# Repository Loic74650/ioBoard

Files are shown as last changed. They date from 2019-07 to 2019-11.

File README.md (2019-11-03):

<h2>ioBoard v1.2</h2>
<h2>I/O board with Ethernet connectivity for home automation applications</h2>
<br />
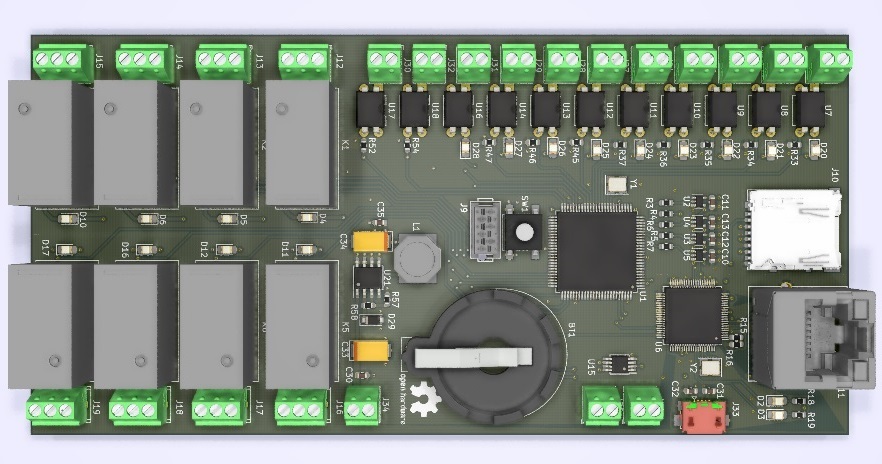
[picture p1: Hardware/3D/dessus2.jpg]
Overview
 <br /><br />
<br />
<h4>Brief description</h4>
<p>Simply put, ioBoard is a mix between an Arduino Mega board, the Ethernet shield and the relay shield + some small additional features (RTC, opto-isolation of digital inputs/outputs, two analog inputs, one Teleinfo input…).<br />
It supports the MQTT protocol and has a set of API functions so that it is easy to control it over the Ethernet for home automation applications for instance.<br />
ioBoard can be programmed to perform tasks at regular intervals such as water the garden or switch on a pump autonomously. <br />
ioBoard also has input pulse counters, typically used to track the consumption of a gas or oil heater, water or even electrical consumption.<br />
ioBoard also has a TeleInfo input, which is a French dedicated energy meter interface to the main electric meter of the house.<br />
Finally, ioBoard has a small web server stored on an SD card, in order to reflect the status of the board I/Os.</p> <br />

<h4>Main specs:</h4>
<p>
<ul>
<li>Atmega2560 16MHz µC</li>
<li>programmable with Arduino IDE (with USB interface)</li>
<li>Ethernet 10M/100M RJ45 internet interface</li>
<li>x8 Relay outputs 230VAC/30VDC 10A – Form-C relays, screw terminal and SMD Status-LED for each (opto-isolated from µC)</li>
<li>x8 opto-isolated digital inputs with SMD Status-LEDs (internal pull-up, HIGH level by default. Ground the input to make it LOW)</li> 
<li>x2 10 bits analog inputs 0-3.3VDC</li>
<li>x2 opto-isolated digital input pulse counters (internal pull-up by default. Ground the input to increment it. Input low-pass filtered at 10Hz max.)</li> 
<li>x1 opto-isolated Télé-Info input</li> 
<li>RTC module (DS1307) for time management with on-board Lithium back-up battery</li> 
<li>Micro SD card slot (Web server) </li>
<li>DIN rail format (PCB Size 143mm x 72mm)</li>
</ul>
</p><br />

<h4>Getting started</h4>
<p>
Before compiling the code and flashing it onto the µC, make sure you have changed the following variables in the code:<br /> 
<ul>
<li>MAC address of the board</li>
<li>IP address of the MQTT broker</li>
<li>Credentials to log into the MQTT broker</li>
</ul>
</p><br />

<h4>MQTT API</h4>
<p>
Below are the Payloads/commands to publish on the "ioBoard/API" topic in Json format in order to launch actions on the ioBoard:<br />
<ul>
<li>{"SetRelayMode":[3,1,500]} -> set the operating mode for a relay. 0 is standard operating mode (ON/OFF) and 1 is PULSE mode. In pulse mode, after a relay has been switched ON, it will automatically switch back to OFF state after a defined time in millisecs. In this example, relay #3 is set to PULSE mode with a switch back time of 500ms</li> 
<li>{"SetRelay":[4,1]}      -> set state of a defined relay. In this example, relay #4 is set to 1</li> 
<li>{"SetRelays":15}        -> set all relays states at once by sending a Byte. Each individual bit reflects the status of one relay. In this example, the first four relays are switched ON and the last four are switched OFF (15 in decimal form corresponds to 00001111 in binary form)</li> 
<li>{"SetC0":0}        		-> set initial value of Counter #0</li>
<li>{"SetC1":2140}        	-> set initial value of Counter #1</li>
<li>{"SetDate":[1,1,1,18,13,32,0]}      -> set date/time of RTC module in the following format: (Day of the month, Day of the week, Month, Year, Hour, Minute, Seconds), in this example: Monday 1st January 2018 - 13h32mn00secs</li>
</ul>
<br />

The status of the I/Os is published on the "ioBoard/IOs" topic in the following Json format:<br />
<ul>
<li>{"Relays":15}       	-> A Byte representing all the relays states. Each individual bit reflects the status of one relay. In this example, the first four relays are ON and the last four are OFF (15 in decimal form corresponds to 00001111 in binary form)</li>
<li>{"DIns":127}       		-> A Byte representing all the digital input states. Each individual bit reflects the status of one input. In this example, the first input state is FALSE and the last seven are TRUE (127 in decimal form corresponds to 01111111 in binary form)</li>
<li>{"C0":1203}       		-> Value of Counter0</li>
<li>{"C1":0}       			-> Value of Counter1</li>
<li>{"AI":[1203,0]}       	-> Values of the Analog Inputs. In this example, AI0 is 1203 and AI1 is 0</li>
<li>{"TI":[ADCO,OPTARIF,ISOUSC,BASE,IINST,PAPP,ADPS,IMAX,PTEC]}      -> TeleInfo data. Refer to this link for more info: https://www.enedis.fr/sites/default/files/Enedis-NOI-CPT_02E.pdf</li>
</ul>
<br />

The above Json commands representing the state of the I/Os are updated as soon as a Digital I/O changes state or every 30 secs for the Analog Inputs.
</p><br />

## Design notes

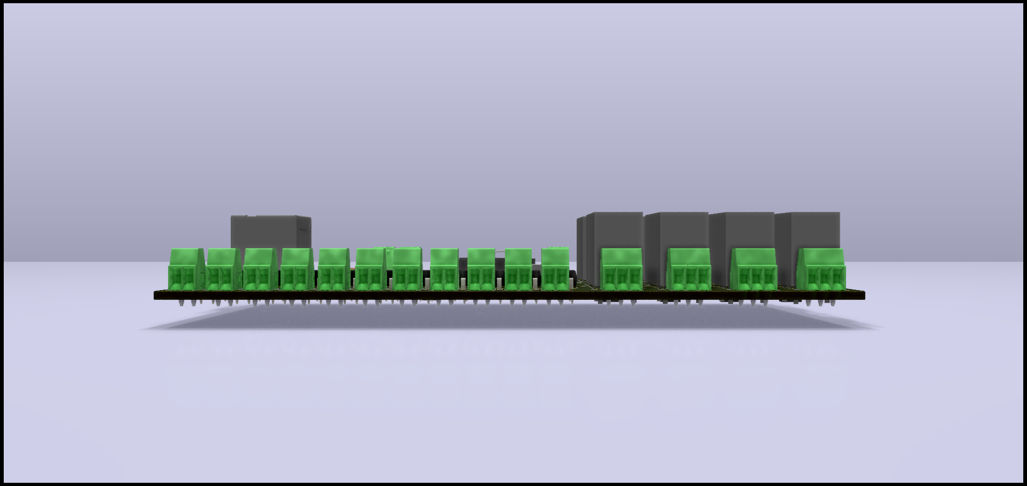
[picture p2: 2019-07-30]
Hardware/3D/gauche.png

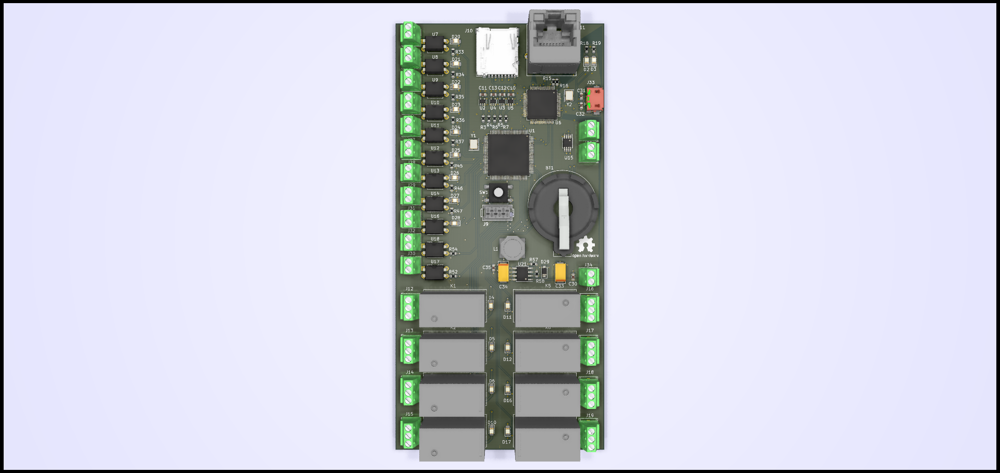
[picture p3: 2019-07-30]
Hardware/3D/dessus.png

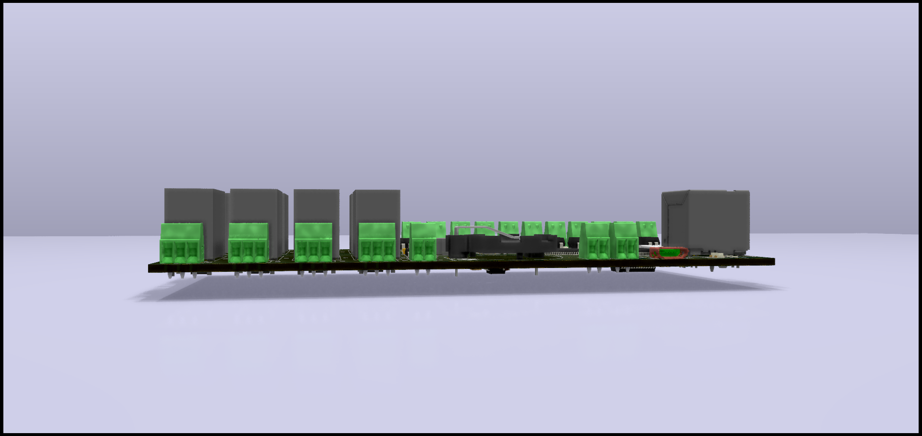
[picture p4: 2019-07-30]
Hardware/3D/droite.png

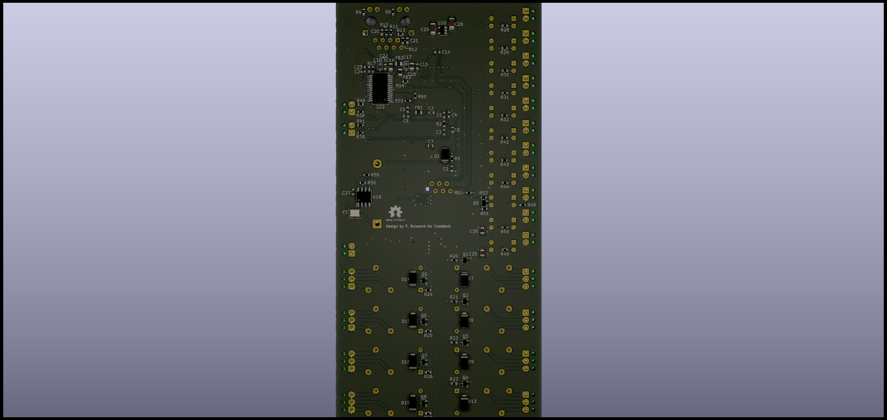
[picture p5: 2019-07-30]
Hardware/3D/dessous.png

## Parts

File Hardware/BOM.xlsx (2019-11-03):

Date: | 2019-06-19
Tool: | Eeschema (5.0.2)-1
Generator: | C:\Program Files\KiCad\bin\scripting\plugins/bom_csv_grouped_by_value_with_fp.py
Component Count: | 188
Ref | Qnty | Value | Cmp name | Footprint | Description | Farnel n° | Prix unitaire | Total
 | 1 | CR2025 | Battery_Cell |  | ~ | 2065170 | 0.52 € | 0.52 €
BT1 | 1 | 103 | KEYSTONE |  |  | 676469 | 2.79 € | 2.79 €
C1, C23, C24, | 3 | 22pF | C |  | Unpolarized capacitor | 2309012 | 0.05 € | 0.16 €
C3, C4, | 2 | 15pF | C |  | Unpolarized capacitor | 1759055 | 0.05 € | 0.09 €
C7, C6, C5, C2, C9, C8, C14, C21, C20, C15, C22, C27, C30, C35, C36 | 14 | 100nF | C |  | Unpolarized capacitor | 2210925 | 0.05 € | 0.65 €
C12, C10, C13, C11, | 4 | 10nF | C |  | Unpolarized capacitor | 9406182 | 0.02 € | 0.08 €
C16, C19, C25, C26, | 4 | 1uF | C |  | Unpolarized capacitor | 2896564 | 0.06 € | 0.25 €
C31, C32, | 2 | 47pF | C |  | Unpolarized capacitor | 1759062 | 0.05 € | 0.10 €
C29, C28, | 2 | 1µF | CP |  | Polarized capacitor | 2491457 | 0.24 € | 0.49 €
C33, C34 | 2 | 10µF | CP |  | Polarized capacitor | 2462775 | 0.22 € | 0.43 €
C17, C18, | 2 | 10µF | CP |  | Polarized capacitor | 2491430 | 0.31 € | 0.63 €
D1, | 1 | RSFBL R3 | DIODE |  | Diode symbol for simulation only. Pin order incompatible with official kicad footprints | 1559142 | 0.09 € | 0.09 €
D2, D3, D6, D11, D10, D16, D5, D12, D17, D4, D20, D21, D22, D23, D24, D25, D26, D27, D28 | 19 | LED | KP-2012LSGC |  | Light emitting diode | 2463991 | 0.09 € | 1.68 €
D9, D14, D13, D18, D8, D15, D19, D7, | 8 | S1JL R3 | DIODE |  | Diode symbol for simulation only. Pin order incompatible with official kicad footprints | 1559153 | 0.07 € | 0.56 €
D29 | 1 | NRVTS2H60ESFT3G |  |  |  | 3003776 | 0.18 € | 0.18 €
FB1, | 1 | 10 µH | Ferrite_Bead_Small |  | Ferrite bead, small symbol | 2215650 | 0.11 € | 0.11 €
FB3, FB2, | 2 | MH2029-300Y | Ferrite_Bead_Small |  | Ferrite bead, small symbol | 2859248 | 0.07 € | 0.13 €
J9, | 1 | ICSP | Conn_02x03_Odd_Even |  | Generic connector, double row, 02x03, odd/even pin numbering scheme (row 1 odd numbers, row 2 even numbers), script generated (kicad-library-utils/schlib/autogen/connector/) | 2473349 | 0.27 € | 0.27 €
J10, | 1 | Micro_SD_Card | Micro_SD_Card |  | Micro SD Card Socket | 2427719 | 1.83 € | 1.83 €
J11, | 1 | 8P8C_LED_Shielded | 8P8C_LED_Shielded |  | RJ connector, 8P8C (8 positions 8 connected), two LEDs, RJ45, Shielded | 2891063 | 1.22 € | 1.22 €
J14, J16, J15, J18, J13, J17, J19, J12, | 8 | MPT 0.5/3-2.54 | Screw_Terminal_01x03 |  | Generic screw terminal, single row, 01x03, script generated (kicad-library-utils/schlib/autogen/connector/) | 3041360 | 1.02 € | 8.16 €
J20, J21, J22, J23, J24, J27, J28, J29, J25, J26, J30, J32, J31, J34 | 14 | MPT 0.5/2-2.54 | Screw_Terminal_01x02 |  | Generic screw terminal, single row, 01x02, script generated (kicad-library-utils/schlib/autogen/connector/) | 3041359 | 0.72 € | 10.14 €
J33, | 1 | micro USB | micro USB |  |  | 2751674 | 0.27 € | 0.27 €
K3, K5, K4, K7, K2, K6, K8, K1, | 8 | OMI-SH-112LM | G5Q-1EU |  | Ultra-miniature, Highly Sensitive SPDT Relay for Signal Circuits | 4446434 | 0.78 € | 6.23 €
L1 | 1 | 47µH | SRU8043 |  |  | 2859240 | 0.78 € | 0.78 €
Q3, Q5, Q4, Q7, Q2, Q6, Q8, Q1, Q9, | 9 | RU1C001UNTCL | Q_NMOS_GSD |  | N-MOSFET transistor, gate/source/drain | 2706680 | 0.09 € | 0.80 €
R1, R38, R40, R39, R41,R53, R56, R55, R57, R58, R62, R63, R64, R65, R66, R67 | 18 | 10K | R |  | Resistor | 2447230 | 0.01 € | 0.18 €
R2, R17, | 2 | 1M | R |  | Resistor | 2073358 |  | 0.00 €
R5, R7, R4, R6, R3, R14, R59, R60, | 8 | 100 | R |  | Resistor | 2694684 | 0.01 € | 0.08 €
R9, R8, R18, R19, R22, R24, R23, R26, R21, R25, R27, R20, | 11 | 1K | R |  | Resistor | 2694685 | 0.01 € | 0.09 €
R13, R12, R11, R10, | 4 | 49.9 | R |  | Resistor | 2447381 | 0.01 € | 0.04 €
R15, | 1 | 12K | R |  | Resistor | 2447243 | 0.01 € | 0.01 €
R16, | 1 | 300 | R |  | Resistor | 2073463 | 0.01 € | 0.01 €
R28, R29, R30, R31, R32, R42, R43, R44, R49, R50, | 10 | 510 | R |  | Resistor | 1469826 | 0.01 € | 0.10 €
R33, R34, R35, R37, R45, R46, R47, R36, R51 | 9 | 1K5 | R |  | Resistor | 2694727 | 0.01 € | 0.09 €
R48, | 1 | 4.7K | R |  | Resistor | 2447385 | 0.01 € | 0.01 €
R54, R52 | 1 | 15K | R |  | Resistor | 2861871 | 0.01 € | 0.01 €
SW1, | 1 | SW_DPST | SW_DPST |  | Double Pole Single Throw (DPST) Switch | 1181017 | 0.63 € | 0.63 €
U1, | 1 | ATmega2560 | ATmega2560-16AU |  | 16MHz, 256kB Flash, 8kB SRAM, 4kB EEPROM, JTAG, TQFP-100 | 1288330 | 10.13 € | 10.13 €
U3, U5, U2, U4, | 4 | 74AHC1G125 | 74AHC1G125 |  | Single Buffer Gate Tri-State, Low-Voltage CMOS | 1893809 | 0.20 € | 0.81 €
U6, | 1 | W5100 | W5100 |  | 10/100Mb Ethernet controller with TCP/IP stack, LQFP-80 |  |  | 5.13 €
U7, U8, U9, U10, U11, U12, U13, U14, U17, U18, | 10 | SFH617A-1 | SFH617A-1 |  | Optocoupler, Phototransistor Output, 5300 VRMS, VCEO 70V, CTR% 40-80, -55 to +110 degree Celcius, UL, BSI, FIMKO, cUL, THT PDIP-4 | 1612481 | 0.26 € | 2.61 €
U16, | 1 | SFH620A-1 | SFH620A-1 |  | Optocoupler, Phototransistor Output, 5300 VRMS, VCEO 70V, CTR% 40-80, -55 to +110 degree Celcius, UL, BSI, FIMKO, cUL, THT PDIP-4 | 1683360 | 0.72 € | 0.72 €
U15, | 1 | LM2904 | LM2904 |  | Low-Power, Dual-Operational Amplifiers, DIP-14/SOIC-14/SSOP-14 | 2709555 | 0.18 € | 0.18 €
U19, | 1 | DS1307+ | DS1307+ |  | 64 x 8, Serial, I2C Real-time clock, 4.5V to 5.5V VCC, 0Â°C to +70Â°C, DIP-8 | 2798723 | 2.81 € | 2.81 €
U20, | 1 | MIC5504-3.3YM5 | MIC5504-3.3YM5 |  | 300mA Low-dropout Voltage Regulator, Vout 3.3V, Vin up to 5.5V, SOT-23 | 2510377 | 0.10 € | 0.10 €
U21, | 1 | AP1509 | AP1509 |  |  | 1825323 | 1.18 € | 1.18 €
U22, | 1 | FT232RL | FT232RL |  |  | 1146032 | 3.93 € | 3.93 €
Y1, | 1 | 16MHz | Crystal |  | Two pin crystal | 2909954 | 0.75 € | 0.75 €
Y2, | 1 | 25MHz | Crystal |  | Two pin crystal | 2909963 | 0.35 € | 0.35 €
Y3, | 1 | 32.768KHz | Crystal |  | Two pin crystal | 2819305 | 0.34 € | 0.34 €
 |  |  |  |  |  |  | TOTAL | 65.61 €

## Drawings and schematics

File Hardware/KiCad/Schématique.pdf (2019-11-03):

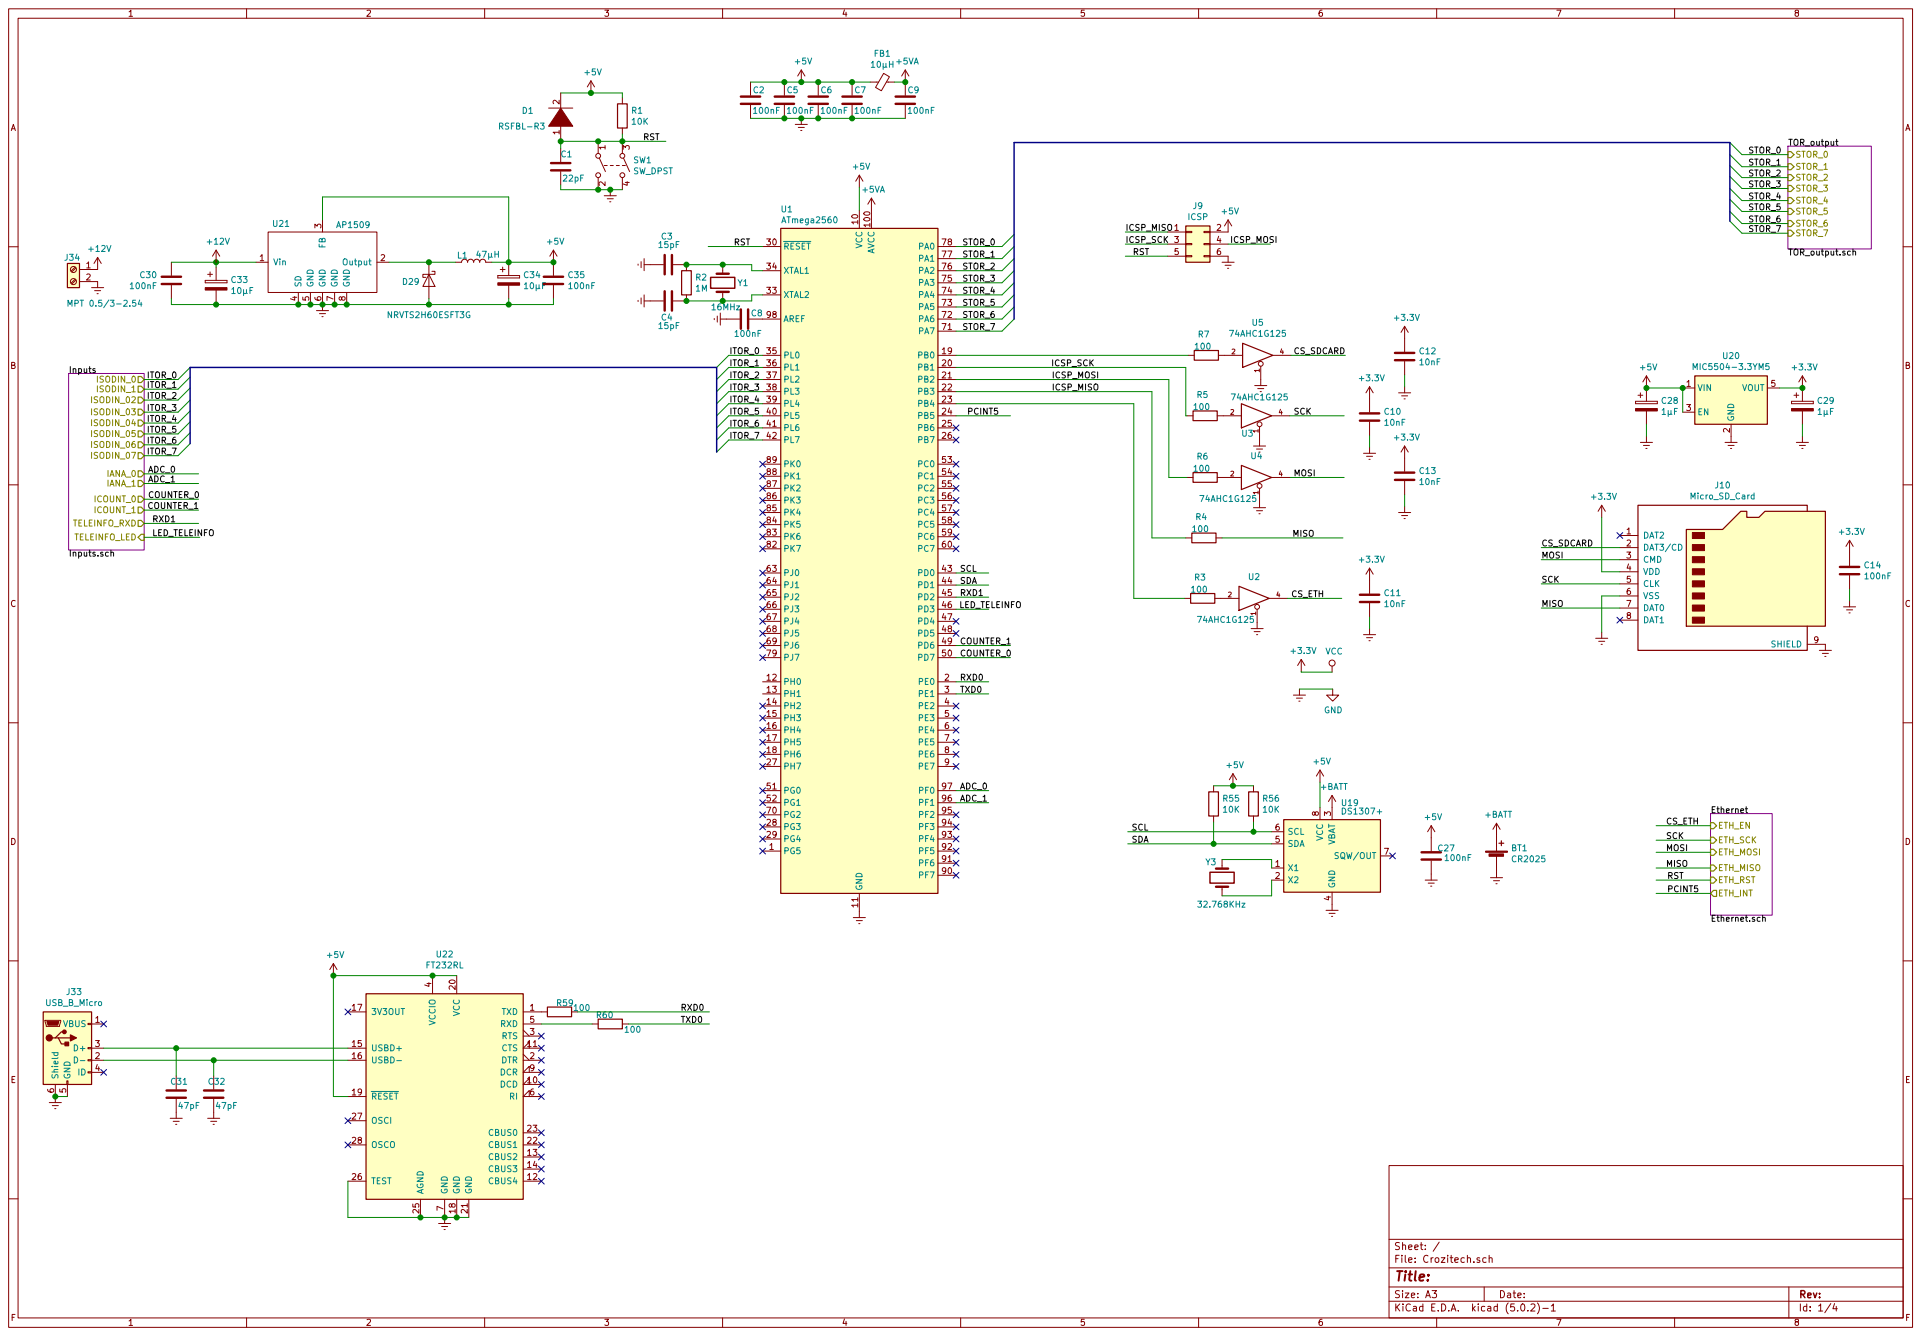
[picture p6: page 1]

4 SDA 5 SCL 6 SQW/OUT 7 VCC

Id: 1/4 Title: File: Crozitech.sch Sheet: /

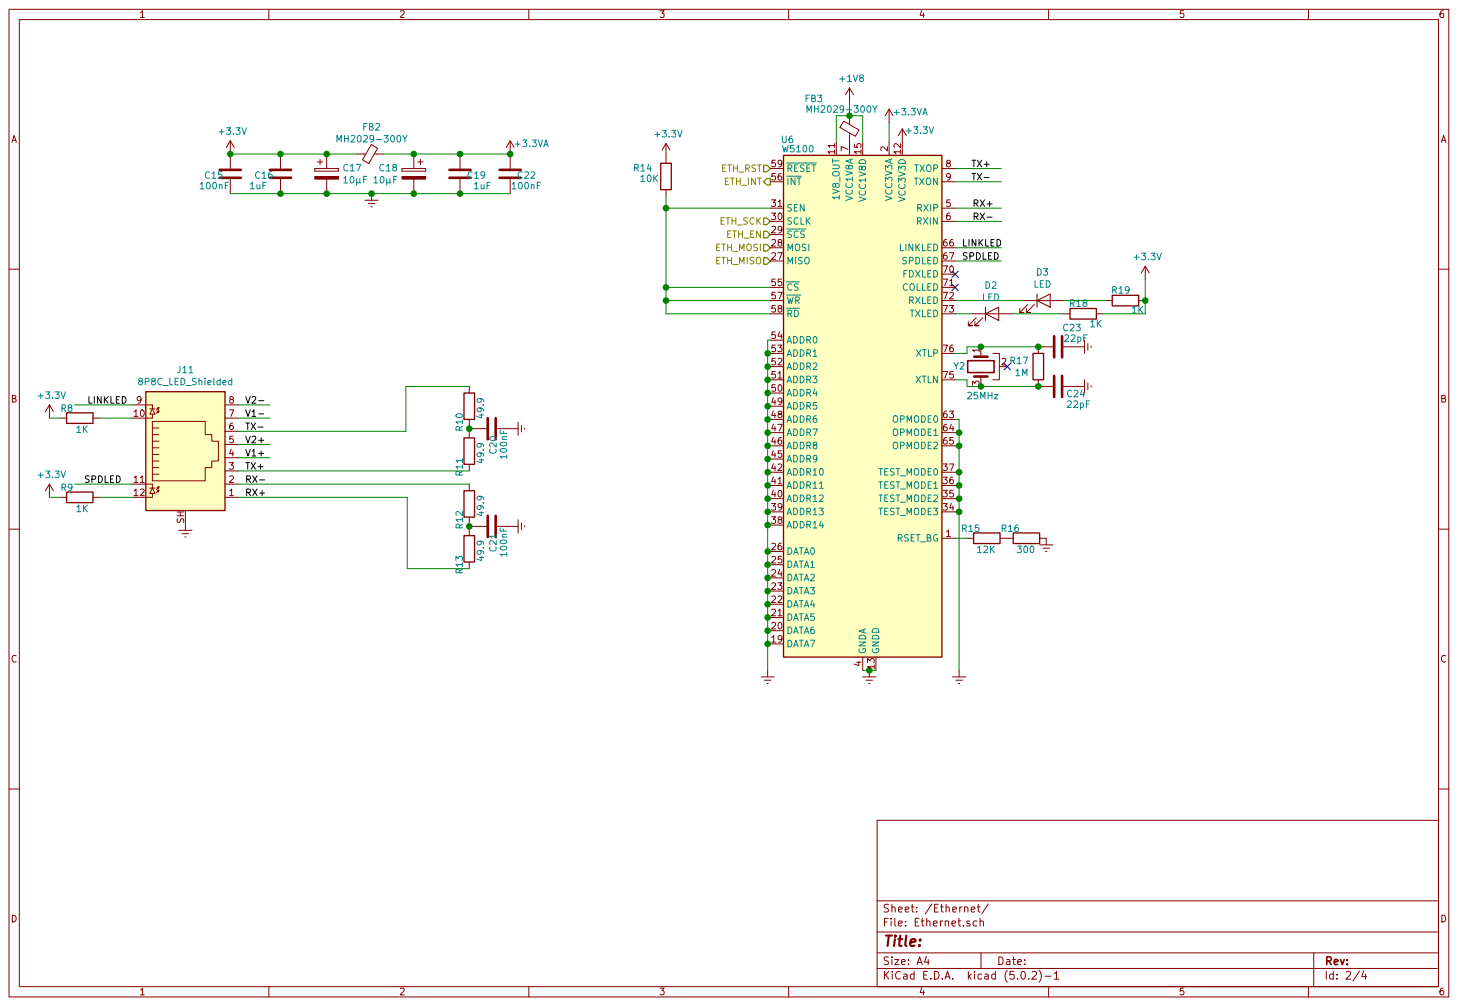
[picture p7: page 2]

Id: 2/4 Title: File: Ethernet.sch Sheet: /Ethernet/ 1

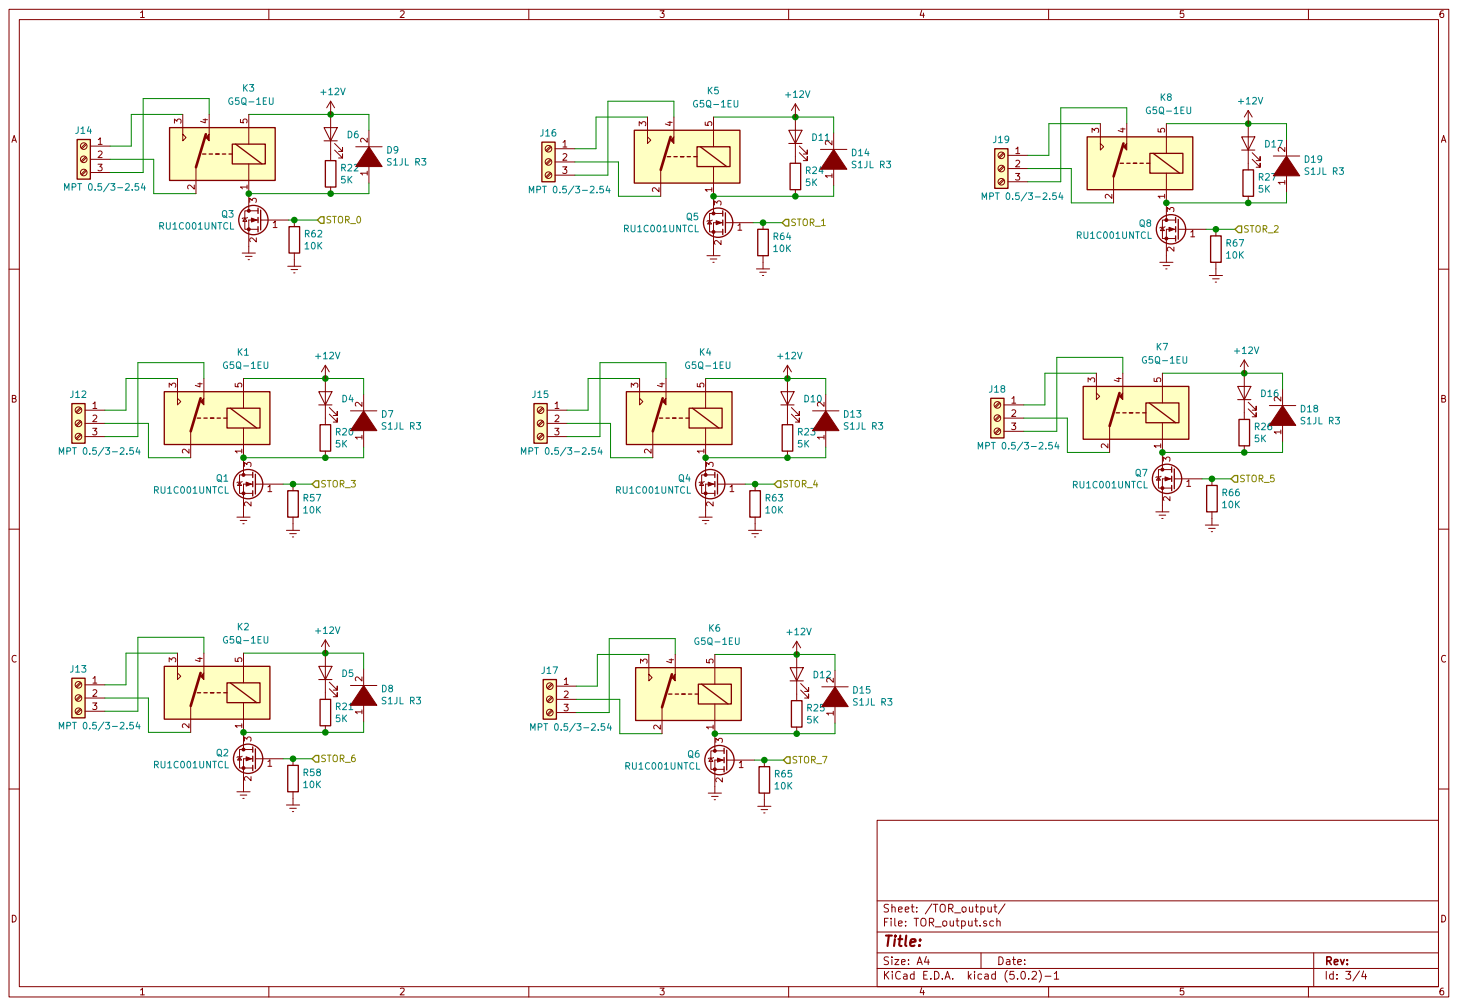
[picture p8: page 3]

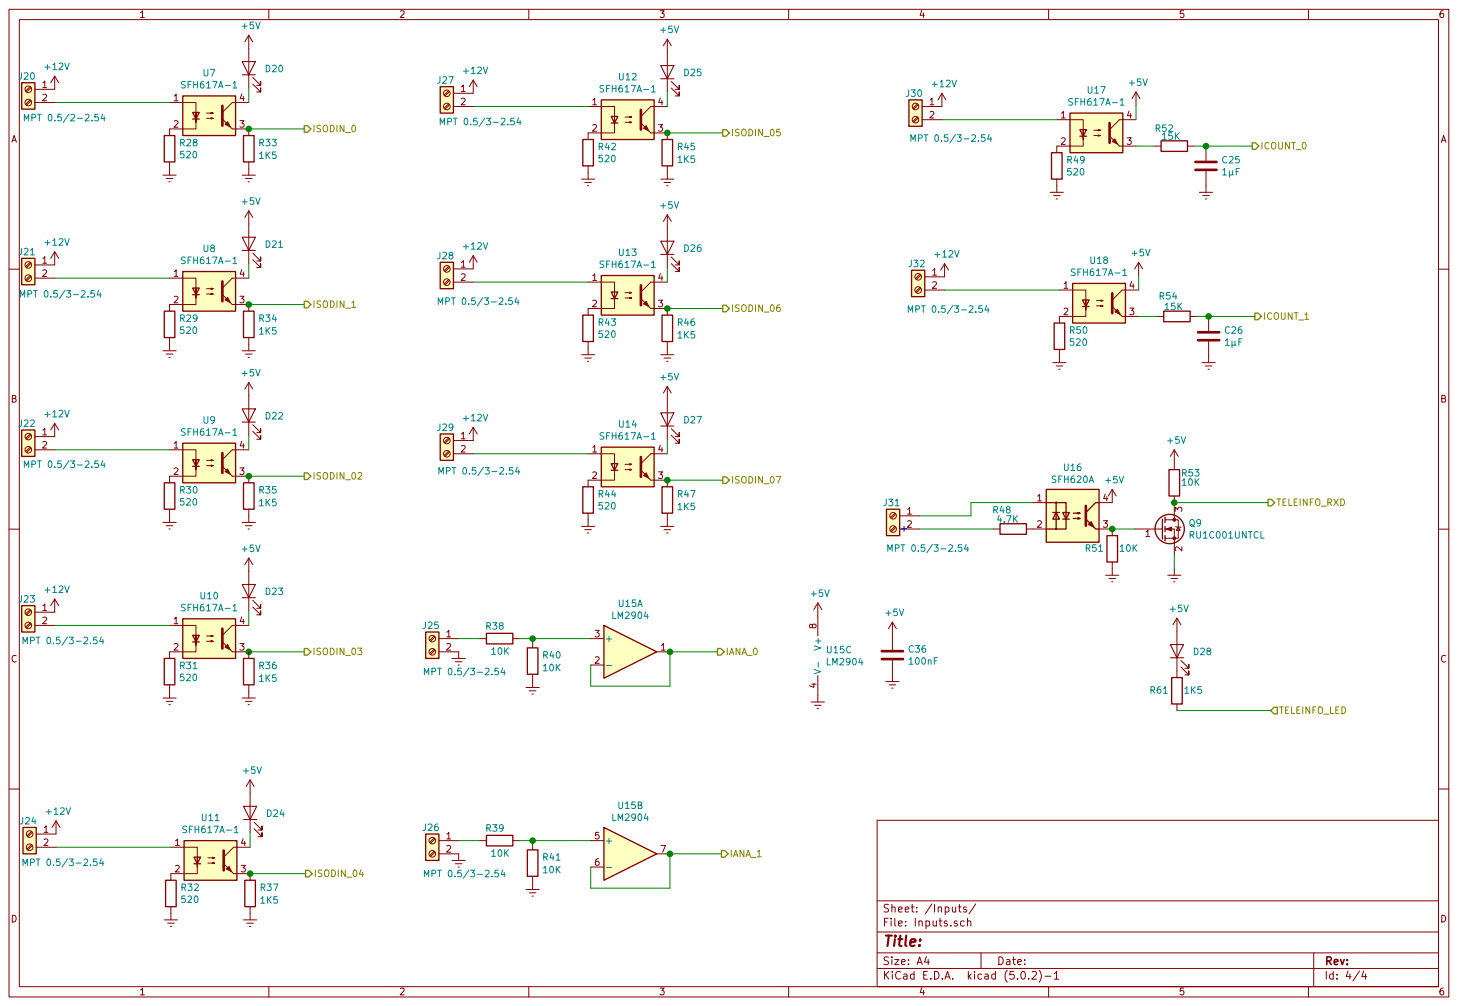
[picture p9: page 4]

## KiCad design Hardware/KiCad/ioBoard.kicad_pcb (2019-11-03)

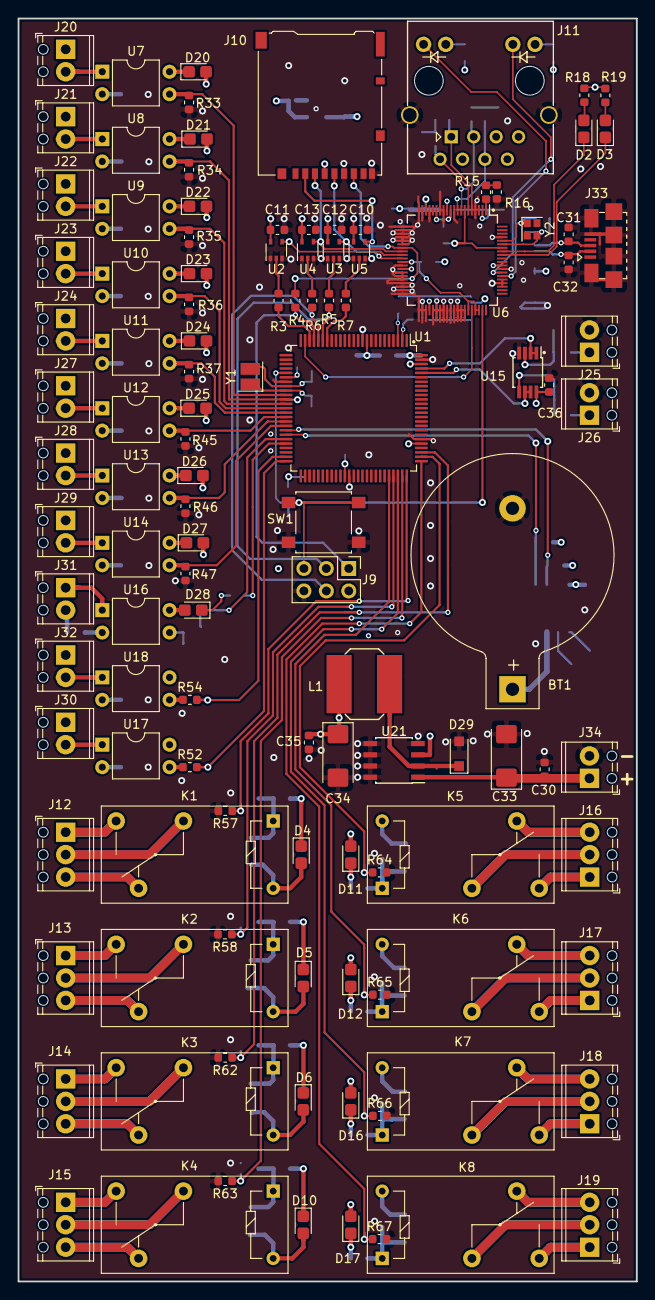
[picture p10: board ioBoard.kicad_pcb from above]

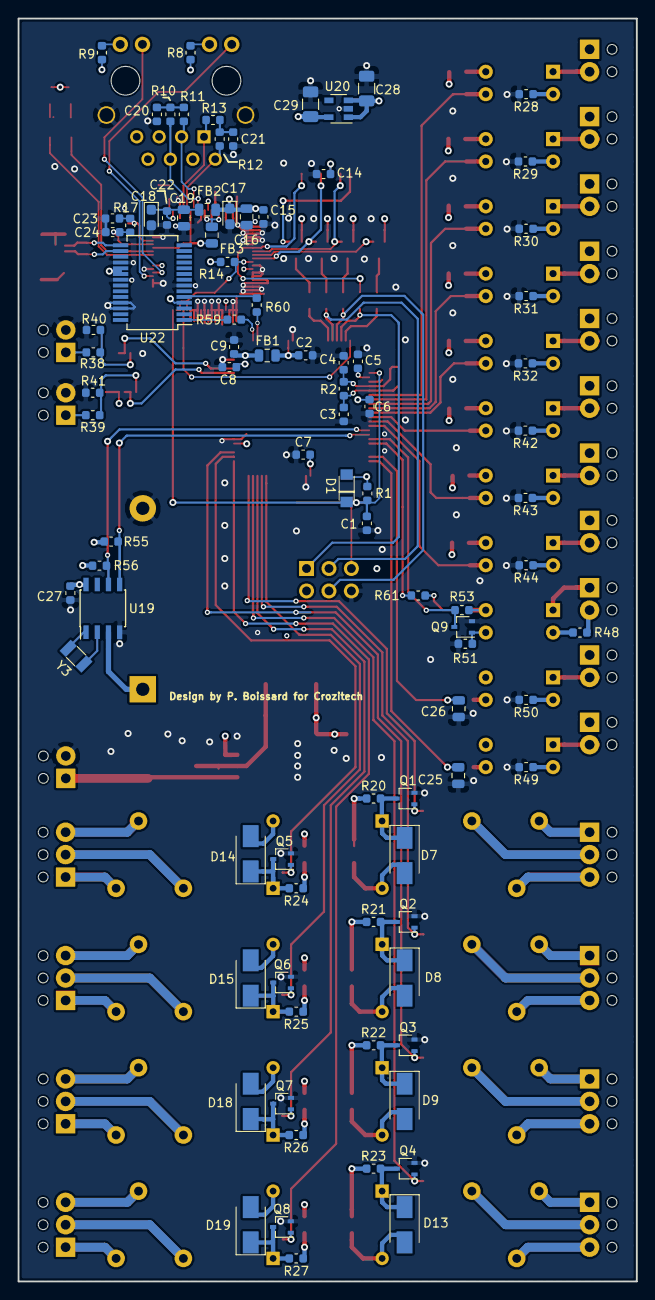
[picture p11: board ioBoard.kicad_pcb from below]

Board: 4 copper layers, 70.0 x 143.0 mm, 206 parts (90 on the bottom side), 159 nets.

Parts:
BT1: CR2025; BatteryHolder_Keystone_103_1x20mm
C1, C23, C24: 22pF; C_0603_1608Metric
C2, C5, C6, C7, C8, C9, C14, C15, C20, C21, C22, C27, C30, C35, C36: 100nF; C_0603_1608Metric
C3, C4: 15pF; C_0603_1608Metric
C10, C11, C12, C13: 10nF; C_0603_1608Metric
C16, C19: 1uF; C_0805_2012Metric
C17, C18: 10µF; CP_EIA-2012-15_AVX-P
C25, C26: 1µF; C_0805_2012Metric
C28, C29: 1µF; C_1206_3216Metric
C31, C32: 47pF; C_0603_1608Metric
C33, C34: 10µF; CP_EIA-6032-15_Kemet-U
D1: RSFBL-R3; D_Sub_SMA
D2, D3, D4, D5, D6, D10, D11, D12, D16, D17, D20, D21, D22, D23, D24, D25, D26, D27, D28: LED; LED_0805_2012Metric_Castellated
D7, D8, D9, D13, D14, D15, D18, D19: S1JL R3; D_SMA
D29: NRVTS2H60ESFT3G; D_SOD-123F
FB1: 10µH; L_0805_2012Metric
FB2, FB3: MH2029-300Y; L_0805_2012Metric
J9: ICSP; PinHeader_2x03_P2.54mm_Vertical
J10: Micro_SD_Card; microSD_HC_Hirose_DM3AT-SF-PEJM5
J11: 8P8C_LED_Shielded; RJ45_Stewart_SS_74301_001
J12, J13, J14, J15, J16, J17, J18, J19: MPT 0.5/3-2.54; TerminalBlock_Phoenix_MPT-0,5-3-2.54_1x03_P2.54mm_Horizontal
J20: MPT 0.5/2-2.54; TerminalBlock_Phoenix_MPT-0,5-2-2.54_1x02_P2.54mm_Horizontal
J21, J22, J23, J24, J25, J26, J27, J28, J29, J30, J31, J32, J34: MPT 0.5/3-2.54; TerminalBlock_Phoenix_MPT-0,5-2-2.54_1x02_P2.54mm_Horizontal
J33: USB_B_Micro; USB_Micro-B_Amphenol_110118192-0001LF_Horizontal
K1, K2, K3, K4, K5, K6, K7, K8: G5Q-1EU; Relay_SPDT_Omron-G5Q-1
L1: 47µH; L_Bourns-SRU8043
Q1, Q2, Q3, Q4, Q5, Q6, Q7, Q8, Q9: RU1C001UNTCL; SOT-323_SC-70
R1, R14, R38, R39, R40, R41, R51, R53, R55, R56, R57, R58, R62, R63, R64, R65, R66, R67: 10K; R_0603_1608Metric
R2, R17: 1M; R_0603_1608Metric
R3, R4, R5, R6, R7, R59, R60: 100; R_0603_1608Metric
R8, R9, R18, R19: 1K; R_0603_1608Metric
R10, R11, R12, R13: 49.9; R_0603_1608Metric
R15: 12K; R_0603_1608Metric
R16: 300; R_0603_1608Metric
R20, R21, R22, R23, R24, R25, R26, R27: 5K; R_0603_1608Metric
R28, R29, R30, R31, R32, R42, R43, R44, R49, R50: 520; R_0603_1608Metric
R33, R34, R35, R36, R37, R45, R46, R47, R61: 1K5; R_0603_1608Metric
R48: 4.7K; R_0603_1608Metric
R52, R54: 15K; R_0603_1608Metric
SW1: SW_DPST; SW_SPST_B3S-1000
U1: ATmega2560; TQFP-100_14x14mm_P0.5mm
U2, U3, U4, U5: 74AHC1G125; SOT-353_SC-70-5
U6: W5100; LQFP-80_10x10mm_P0.4mm
U7, U8, U9, U10, U11, U12, U13, U14, U17, U18: SFH617A-1; DIP-4_W7.62mm
U15: LM2904; MSOP-8_3x3mm_P0.65mm
U16: SFH620A; DIP-4_W7.62mm
U19: DS1307+; SOIC-8_3.9x4.9mm_P1.27mm
U20: MIC5504-3.3YM5; SOT-23-5
U21: AP1509; SOIC-8_3.9x4.9mm_P1.27mm
U22: FT232RL; SSOP-28_5.3x10.2mm_P0.65mm
Y1: 16MHz; Crystal_SMD_2520-4Pin_2.5x2.0mm
Y2: 25MHz; Crystal_SMD_2016-4Pin_2.0x1.6mm
Y3: 32.768KHz; Crystal_SMD_3215-2Pin_3.2x1.5mm

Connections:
+1V8: FB3.1, U6.11, U6.15, U6.16, U6.33, U6.69
+3.3VA: C18.1, C19.1, C22.1, FB2.2, U6.2
+3V3: C10.1, C11.1, C12.1, C13.1, C14.1, C15.1, C16.1, C17.1, C29.1, FB2.1, J10.4, R8.1, R9.1, R14.2, R18.1, R19.1, U2.5, U3.5, U4.5, U5.5, U6.12, U6.18, U6.44, U20.5
+5V: C2.2, C5.2, C6.2, C7.2, C27.2, C28.1, C34.1, C35.1, C36.1, D1.2, D20.2, D21.2, D22.2, D23.2, D24.2, D25.2, D26.2, D27.2, D28.2, FB1.2, J9.2, L1.2, R1.1, R53.2, R55.1, R56.1, U1.10, U1.31, U1.61, U1.80, U15.8, U16.4, U17.4, U18.4, U19.8, U20.1, U20.3, U21.3, U22.4, U22.19, U22.20
+5VA: C9.2, FB1.1, U1.100
+12V: C30.1, C33.1, D4.2, D5.2, D6.2, D7.2, D8.2, D9.2, D10.2, D11.2, D12.2, D13.2, D14.2, D15.2, D16.2, D17.2, D18.2, D19.2, J20.1, J21.1, J22.1, J23.1, J24.1, J27.1, J28.1, J29.1, J30.1, J32.1, J34.1, K1.5, K2.5, K3.5, K4.5, K5.5, K6.5, K7.5, K8.5, U21.1
+BATT: BT1.1, U19.3
/ADC_0: U1.97, U15.1, U15.2
/ADC_1: U1.96, U15.6, U15.7
/COUNTER_0: C25.1, R52.2, U1.50
/COUNTER_1: C26.1, R54.2, U1.49
/CS_ETH: U2.4, U6.29
/CS_SDCARD: J10.2, U5.4
/Ethernet/LINKLED: J11.9, U6.66
/Ethernet/RX+: J11.1, R13.1, U6.5
/Ethernet/RX-: J11.2, R12.2, U6.6
/Ethernet/SPDLED: J11.11, U6.67
/Ethernet/TX+: J11.3, R11.1, U6.8
/Ethernet/TX-: J11.6, R10.2, U6.9
/ICSP_MISO: J9.1, R4.1, U1.22
/ICSP_MOSI: J9.4, R6.1, U1.21
/ICSP_SCK: J9.3, R5.1, U1.20
/ITOR_0: R33.1, U1.35, U7.3
/ITOR_1: R34.1, U1.36, U8.3
/ITOR_2: R35.1, U1.37, U9.3
/ITOR_3: R36.1, U1.38, U10.3
/ITOR_4: R37.1, U1.39, U11.3
/ITOR_5: R45.1, U1.40, U12.3
/ITOR_6: R46.1, U1.41, U13.3
/ITOR_7: R47.1, U1.42, U14.3
/LED_TELEINFO: R61.1, U1.46
/MISO: J10.7, R4.2, U6.27
/MOSI: J10.3, U4.4, U6.28
/PCINT5: U1.24, U6.56
/RST: C1.2, D1.1, J9.5, R1.2, SW1.1, SW1.3, U1.30, U6.59
/RXD0: R59.1, U1.2
/RXD1: Q9.3, R53.1, U1.45
/SCK: J10.5, U3.4, U6.30
/SCL: R56.2, U1.43, U19.6
/SDA: R55.2, U1.44, U19.5
/STOR_0: Q3.1, R62.1, U1.78
/STOR_1: Q5.1, R64.1, U1.77
/STOR_2: Q8.1, R67.1, U1.76
/STOR_3: Q1.1, R57.1, U1.75
/STOR_4: Q4.1, R63.1, U1.74
/STOR_5: Q7.1, R66.1, U1.73
/STOR_6: Q2.1, R58.1, U1.72
/STOR_7: Q6.1, R65.1, U1.71
/TXD0: R60.2, U1.3
Earth: BT1.2, C1.1, C2.1, C3.1, C4.1, C5.1, C6.1, C7.1, C8.2, C9.1, C10.2, C11.2, C12.2, C13.2, C14.2, C15.2, C16.2, C17.2, C18.2, C19.2, C20.2, C21.2, C22.2, C23.1, C24.1, C25.2, C26.2, C27.1, C28.2, C29.2, C30.2, C31.1, C32.1, C33.2, C34.2, C35.2, C36.2, D29.2, J9.6, J10.6, J10.9, J11.SH, J25.2, J26.2, J33.5, J33.6, J34.2, Q1.2, Q2.2, Q3.2, Q4.2, Q5.2, Q6.2, Q7.2, Q8.2, Q9.2, R16.2, R28.2, R29.2, R30.2, R31.2, R32.2, R33.2, R34.2, R35.2, R36.2, R37.2, R40.2, R41.2, R42.2, R43.2, R44.2, R45.2, R46.2, R47.2, R49.2, R50.2, R51.1, R57.2, R58.2, R62.2, R63.2, R64.2, R65.2, R66.2, R67.2, SW1.2, SW1.4, U1.11, U1.32, U1.62, U1.81, U1.99, U2.1, U2.3, U3.1, U3.3, U4.1, U4.3, U5.1, U5.3, U6.4, U6.10, U6.13, U6.14, U6.17, U6.19, U6.20, U6.21, U6.22, U6.23, U6.24, U6.25, U6.26, U6.32, U6.34, U6.35, U6.36, U6.37, U6.38, U6.39, U6.40, U6.41, U6.42, U6.43, U6.45, U6.46, U6.47, U6.48, U6.49, U6.50, U6.51, U6.52, U6.53, U6.54, U6.63, U6.64, U6.65, U6.68, U6.77, U15.4, U19.4, U20.2, U21.4, U21.5, U21.6, U21.7, U21.8, U22.7, U22.18, U22.21, U22.25, U22.26
unnamed: C3.2, R2.1, U1.34, Y1.1
unnamed: C4.2, R2.2, U1.33, Y1.2
unnamed: C8.1, U1.98
unnamed: C20.1, R10.1, R11.2
unnamed: C21.1, R12.1, R13.2
unnamed: C23.2, R17.1, U6.76, Y2.1
unnamed: C24.2, R17.2, U6.75, Y2.3
unnamed: C31.2, J33.3, U22.15
unnamed: C32.2, J33.2, U22.16
unnamed: D2.1, U6.73
unnamed: D2.2, R18.2
unnamed: D3.1, U6.72
unnamed: D3.2, R19.2
unnamed: D4.1, R20.1
unnamed: D5.1, R21.1
unnamed: D6.1, R22.1
unnamed: D7.1, K1.1, Q1.3, R20.2
unnamed: D8.1, K2.1, Q2.3, R21.2
unnamed: D9.1, K3.1, Q3.3, R22.2
unnamed: D10.1, R23.1
unnamed: D11.1, R24.1
unnamed: D12.1, R25.1
unnamed: D13.1, K4.1, Q4.3, R23.2
unnamed: D14.1, K5.1, Q5.3, R24.2
unnamed: D15.1, K6.1, Q6.3, R25.2
unnamed: D16.1, R26.1
unnamed: D17.1, R27.1
unnamed: D18.1, K7.1, Q7.3, R26.2
unnamed: D19.1, K8.1, Q8.3, R27.2
unnamed: D20.1, U7.4
unnamed: D21.1, U8.4
unnamed: D22.1, U9.4
unnamed: D23.1, U10.4
unnamed: D24.1, U11.4
unnamed: D25.1, U12.4
unnamed: D26.1, U13.4
unnamed: D27.1, U14.4
unnamed: D28.1, R61.2
unnamed: D29.1, L1.1, U21.2
unnamed: FB3.2, U6.7, U6.74
unnamed: J11.10, R8.2
unnamed: J11.12, R9.2
unnamed: J12.1, K1.3
unnamed: J12.2, K1.2
unnamed: J12.3, K1.4
unnamed: J13.1, K2.3
unnamed: J13.2, K2.2
unnamed: J13.3, K2.4
unnamed: J14.1, K3.3
unnamed: J14.2, K3.2
unnamed: J14.3, K3.4
unnamed: J15.1, K4.3
unnamed: J15.2, K4.2
unnamed: J15.3, K4.4
unnamed: J16.1, K5.3
unnamed: J16.2, K5.2
unnamed: J16.3, K5.4
unnamed: J17.1, K6.3
unnamed: J17.2, K6.2
unnamed: J17.3, K6.4
unnamed: J18.1, K7.3
unnamed: J18.2, K7.2
unnamed: J18.3, K7.4
unnamed: J19.1, K8.3
unnamed: J19.2, K8.2
unnamed: J19.3, K8.4
unnamed: J20.2, U7.1
unnamed: J21.2, U8.1
unnamed: J22.2, U9.1
unnamed: J23.2, U10.1
unnamed: J24.2, U11.1
unnamed: J25.1, R38.1
unnamed: J26.1, R39.1
unnamed: J27.2, U12.1
unnamed: J28.2, U13.1
unnamed: J29.2, U14.1
unnamed: J30.2, U17.1
unnamed: J31.1, U16.1
unnamed: J31.2, R48.1
unnamed: J32.2, U18.1
unnamed: Q9.1, R51.2, U16.3
unnamed: R3.1, U1.23
unnamed: R3.2, U2.2
unnamed: R5.2, U3.2
unnamed: R6.2, U4.2
unnamed: R7.1, U1.19
unnamed: R7.2, U5.2
unnamed: R14.1, U6.31, U6.55, U6.57, U6.58
unnamed: R15.1, U6.1
unnamed: R15.2, R16.1
unnamed: R28.1, U7.2
unnamed: R29.1, U8.2
unnamed: R30.1, U9.2
unnamed: R31.1, U10.2
unnamed: R32.1, U11.2
unnamed: R38.2, R40.1, U15.3
unnamed: R39.2, R41.1, U15.5
unnamed: R42.1, U12.2
unnamed: R43.1, U13.2
unnamed: R44.1, U14.2
unnamed: R48.2, U16.2
unnamed: R49.1, U17.2
unnamed: R50.1, U18.2
unnamed: R52.1, U17.3
unnamed: R54.1, U18.3
unnamed: R59.2, U22.1
unnamed: R60.1, U22.5
unnamed: U19.1, Y3.1
unnamed: U19.2, Y3.2
